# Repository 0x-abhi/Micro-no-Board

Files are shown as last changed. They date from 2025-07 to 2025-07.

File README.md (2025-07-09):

# Micro-no Board (µNO Board)- An Open Source Arduino-Compatible Development Platform

Welcome to the official documentation for the **µNO Board** (pronounced "Micro-no Board"). This open-source project presents a minimalistic, hardware-level implementation of the popular Arduino Uno, centered around the **ATmega328P-PU** microcontroller. Engineered and documented by **Abhishek Tomar**, this project is a comprehensive platform for electronics students and embedded systems learners seeking to understand the internal architecture and design of a microcontroller development board.

---

## 📚 Table of Contents

1. [Project Overview](#project-overview)
2. [Technical Features](#technical-features)
3. [Detailed Schematic Breakdown](#detailed-schematic-breakdown)

   * [Power Supply Circuit](#power-supply-circuit)
   * [Microcontroller Core](#microcontroller-core)
   * [Oscillator Configuration](#oscillator-configuration)
   * [Reset Mechanism](#reset-mechanism)
   * [FTDI Serial Programming Header](#ftdi-serial-programming-header)
   * [ISP Bootloader Interface](#isp-bootloader-interface)
   * [Status LED Indicator](#status-led-indicator)
4. [Arduino to ATmega328P Pin Mapping](#arduino-to-atmega328p-pin-mapping)
5. [Burning the Bootloader](#burning-the-bootloader)
6. [Uploading Programs via FTDI](#uploading-programs-via-ftdi)
7. [Understanding ISP and FTDI Protocols](#understanding-isp-and-ftdi-protocols)
8. [Accessing Design Files](#accessing-design-files)
9. [Contributions and Collaboration](#contributions-and-collaboration)
10. [License](#license)

---

## 🔍 Project Overview

The **µNO Board** replicates the functionality of the Arduino Uno but strips it to its essentials. Rather than relying on a premade Arduino module, this project demonstrates the discrete components necessary to build a fully functional development board from the ground up:

* Power regulation and filtering
* Stable clock generation
* GPIO and ADC decoupling
* Reset and auto-reset mechanisms
* Programming via serial (FTDI) or SPI (ISP)

It serves as both a learning tool and a production-ready embedded platform.

---

## ⚙️ Technical Features

* **Microcontroller**: ATmega328P-PU (8-bit AVR RISC architecture)
* **Voltage Regulation**: AMS1117-5.0V LDO regulator
* **System Clock**: External 16 MHz crystal
* **Programming Interfaces**: FTDI (UART) and ISP (SPI)
* **Manual Reset Button**: Physical switch for hardware resets
* **Input Voltage Range**: 6V to 15V (via VIN pin)
* **Regulated Output**: +5V for MCU and peripherals
* **GPIO Access**: Digital pins D0-D13, Analog pins A0-A5
* **Status Indicator**: Onboard LED that Indicates power ON/OFF

---

## 🔧 Detailed Schematic Breakdown

### 🔌 Power Supply Circuit

* **AMS1117-5.0V Regulator (U2)**

  * Converts input voltage (up to 15V) to 5V regulated output.
  * Essential for powering the MCU and peripherals.
* **Input/Output Capacitors**:

  * **C7, C8 (10uF)**: Stabilize input (VIN) and output (VOUT).
  * Filter transient fluctuations and reduce switching noise.

### 🧠 Microcontroller Core (ATmega328P)

* **Power Pins**:

  * **VCC (Pin 7)**: Main power input
  * **AVCC (Pin 20)**: Power supply for the ADC block
  * **GND (Pins 8 & 22)**: Common ground
* **Bypass Capacitors**:

  * **C3, C4, C6 (100nF)**: Placed near VCC and AVCC to suppress high-frequency noise.

### ⏱️ Oscillator Configuration

* **Crystal Oscillator (Y1, 16 MHz)**

  * External clock source for the MCU, ensures stable system timing
* **Load Capacitors (C1, C2 = 22pF)**

  * Ensure proper startup and oscillation of the crystal

### 🔁 Reset Mechanism

* **R1 (10kΩ)**: Pull-up resistor on RESET pin
* **SW1**: Push-button reset (pulls RESET to GND when pressed)
* **C5 (100nF)**: Coupled with FTDI DTR pin for auto-reset during code upload

### 🔄 FTDI Serial Programming Header (J5)

* **6-pin Header**: GND, VCC, RX, TX, DTR, CTS
* **Function**: Enables uploading sketches via UART after bootloader is flashed
* **Connection Tip**: Ensure TX (FTDI) connects to RX (MCU) and vice versa

### 💾 ISP Bootloader Interface (J1)

* **Standard 6-pin ISP Header**

  * MISO, MOSI, SCK, RESET, VCC, GND
* **Purpose**: Used for flashing the bootloader or burning hex files directly via SPI

---

## 🧩 Arduino to ATmega328P Pin Mapping

| Arduino | ATmega328P Pin | Port | Description |
| --- | --- | --- | --- |
| D0 | 2 | PD0 | UART RX |
| D1 | 3 | PD1 | UART TX |
| D2-D7 | 4-9 | PD2-PD7 | Digital I/O |
| D8-D13  | 14-19 | PB0-PB5 | SPI & I/O |
| A0-A5 | 23-28 | PC0-PC5 | ADC & I2C |
| RESET | 1 | PC6 | System Reset |
| AREF | 21 | - | Analog Reference |

---

## 🔥 Burning the Bootloader

### 💡 What is a Bootloader?

A bootloader is a small program that resides in the MCU’s flash memory, allowing firmware to be uploaded via UART rather than ISP.

### 🔧 Required Tools

* USBasp Programmer or Arduino-as-ISP

### 🧭 Step-by-Step Guide

1. Connect the ISP header on the board to your programmer.
2. Launch Arduino IDE.
3. Go to **Tools > Board > Arduino Uno**.
4. Under **Programmer**, select **USBasp** (or Arduino as ISP).
5. Click **Burn Bootloader**.

Once burned, your microcontroller can now be programmed through FTDI.

---

## ⬆️ Uploading Programs via FTDI

### 🛠️ Required Hardware

* FTDI USB-to-Serial Converter

### Wiring:

* FTDI TX → MCU RX
* FTDI RX → MCU TX
* DTR → RESET (via 100nF capacitor)
* VCC, GND connected properly

### Upload Steps:

1. Open Arduino IDE and select **Arduino Uno** as the board.
2. Choose the correct **COM Port**.
3. Click **Upload**.

The auto-reset circuit will handle entry into the bootloader automatically.

---

## 🧠 Understanding ISP and FTDI Protocols

### ISP (In-System Programming)

* **Protocol**: SPI-based (MOSI, MISO, SCK)
* **Use Case**: Burning bootloaders or uploading compiled firmware directly
* **Requires**: External programmer

### FTDI (USB-to-UART)

* **Protocol**: UART-based (TX/RX)
* **Use Case**: Uploading code to bootloaded MCUs
* **Advantage**: No extra hardware once bootloader is installed

---
## 🔮 Future Improvements and Expansion Ideas

As a learning platform and minimal Arduino-compatible board, the µNO Board has room for useful upgrades. Here are some potential enhancements that could improve its functionality, usability, and professional quality:

### 🔧 Hardware Improvements

- **⚡ Onboard USB-to-Serial (FTDI)**  
  Add a built-in CH340 or CP2102 IC for USB programming, eliminating the need for an external FTDI adapter.

- **🔋 3.3V Voltage Regulator**  
  Add an LDO regulator (e.g., AMS1117-3.3V) to support 3.3V sensors or modules on the same board.

- **🛡️ Reverse Polarity Protection**  
  Include a Schottky diode or P-MOSFET to protect the board from accidental reverse voltage input.

- **🧲 TVS Diodes or ESD Protection**  
  Protect sensitive GPIOs and the USB interface from electrostatic discharge or voltage spikes.

- **📦 Mounting Hole Grounding**  
  Connect metal mounting holes to GND for improved shielding and mechanical stability.

- **🧠 Additional GPIO Headers / Expansion Ports**  
  Break out I2C, SPI, ADC, and power lines to dedicated connectors for sensor/module expansion.

---

### 🖥️ Firmware & Bootloader Enhancements

- **⏱️ Optiboot Bootloader**  
  Use the smaller Optiboot variant to save flash memory and enable faster serial uploads (up to 115200 baud).

- **🧩 Arduino Board Package Support**  
  Create a custom board definition file (`boards.txt`) to add µNO as an official option in the Arduino IDE.

---

These enhancements can transform the µNO Board from a minimalist learning tool into a feature-rich, professional-grade embedded system. Explore, experiment, and evolve your design! 🚀

---

## 📁 Accessing Design Files

Your repository includes the following:

* `KiCad/`: Schematic and PCB design files
* `Gerber/`: Fabrication-ready output files
* `3D_Images/`: Visual renders of the board
* `README.md`: This documentation

📸 Board Images:

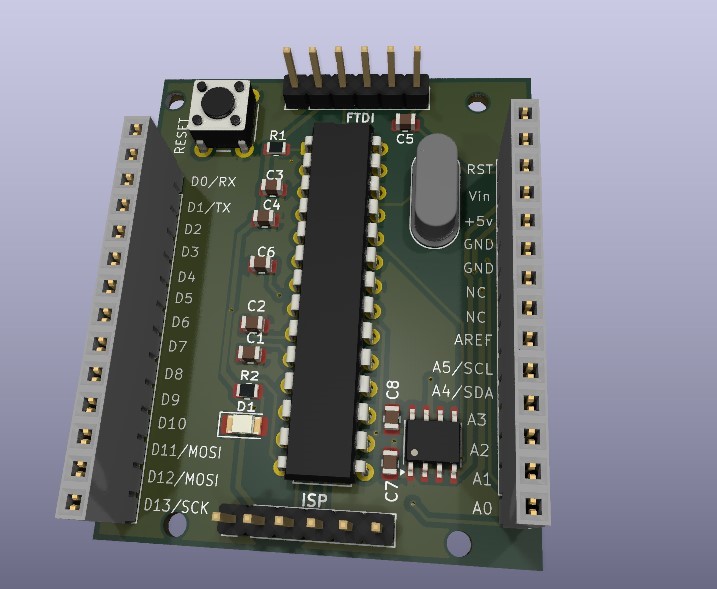
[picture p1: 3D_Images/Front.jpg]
Front View
* 
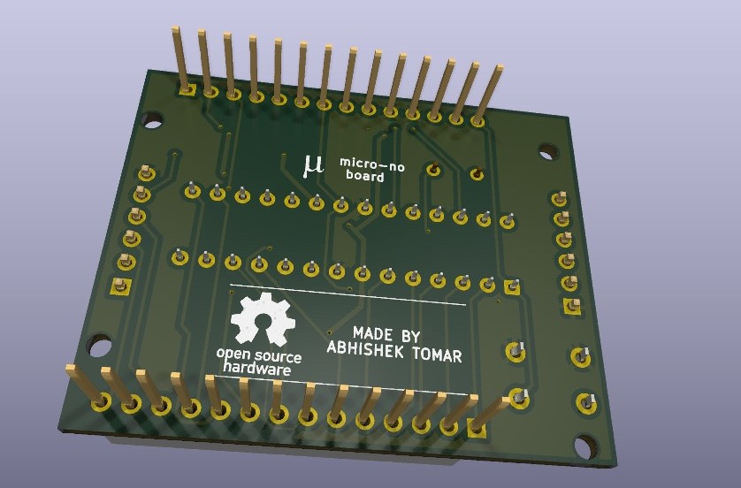
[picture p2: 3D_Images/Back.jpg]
Back View
* 
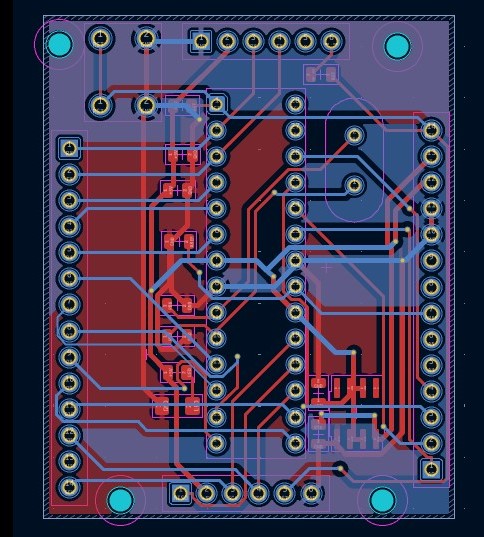
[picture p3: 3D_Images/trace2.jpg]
PCB Traces
* 

---

## 🤝 Contributions and Collaboration

Contributions are welcome! Feel free to fork the repository, submit pull requests, or raise issues for bugs, suggestions, or improvements.

---

## 📜 License

This project is licensed under the **CERN-OHL-S v2** open hardware license. This ensures:

* Freedom to study, modify, manufacture, and distribute
* Requirement to share changes under the same license

---

❤️ Created with passion by Abhishek Tomar — Just a learner like you.

🌟 **Support This Project!**

If this project helped you learn, build, or get inspired, please ⭐ star the repository and share it!

Together, we make open hardware accessible and empowering for all. 💪✨

Happy Hacking 🚀

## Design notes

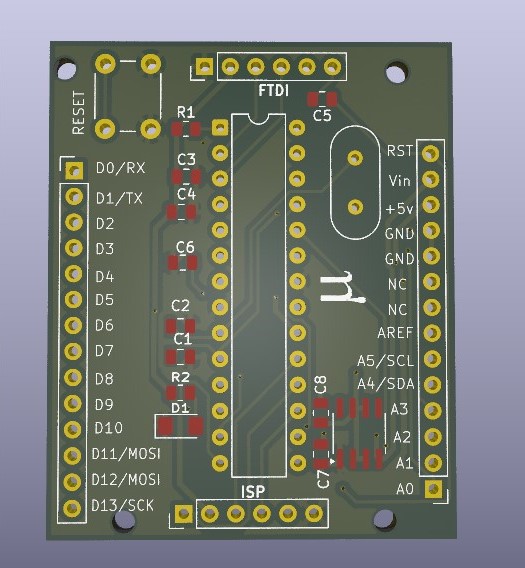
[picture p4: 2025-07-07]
3D_Images/PCB.jpg

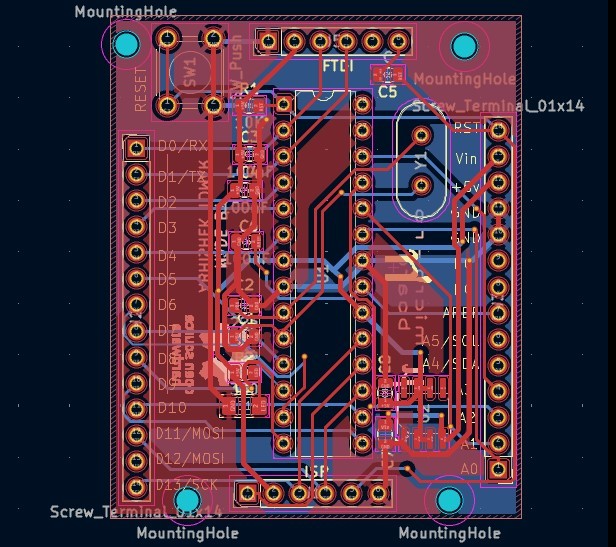
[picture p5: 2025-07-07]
3D_Images/trace1.jpg

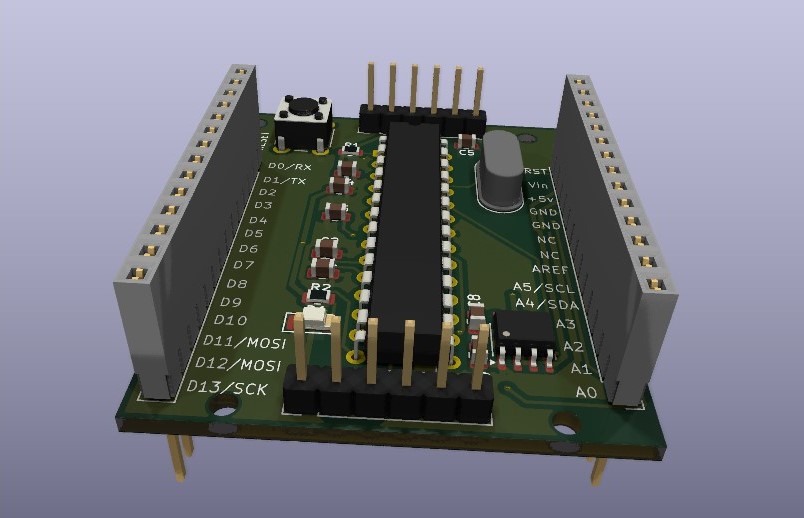
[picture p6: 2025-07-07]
3D_Images/Side.jpg

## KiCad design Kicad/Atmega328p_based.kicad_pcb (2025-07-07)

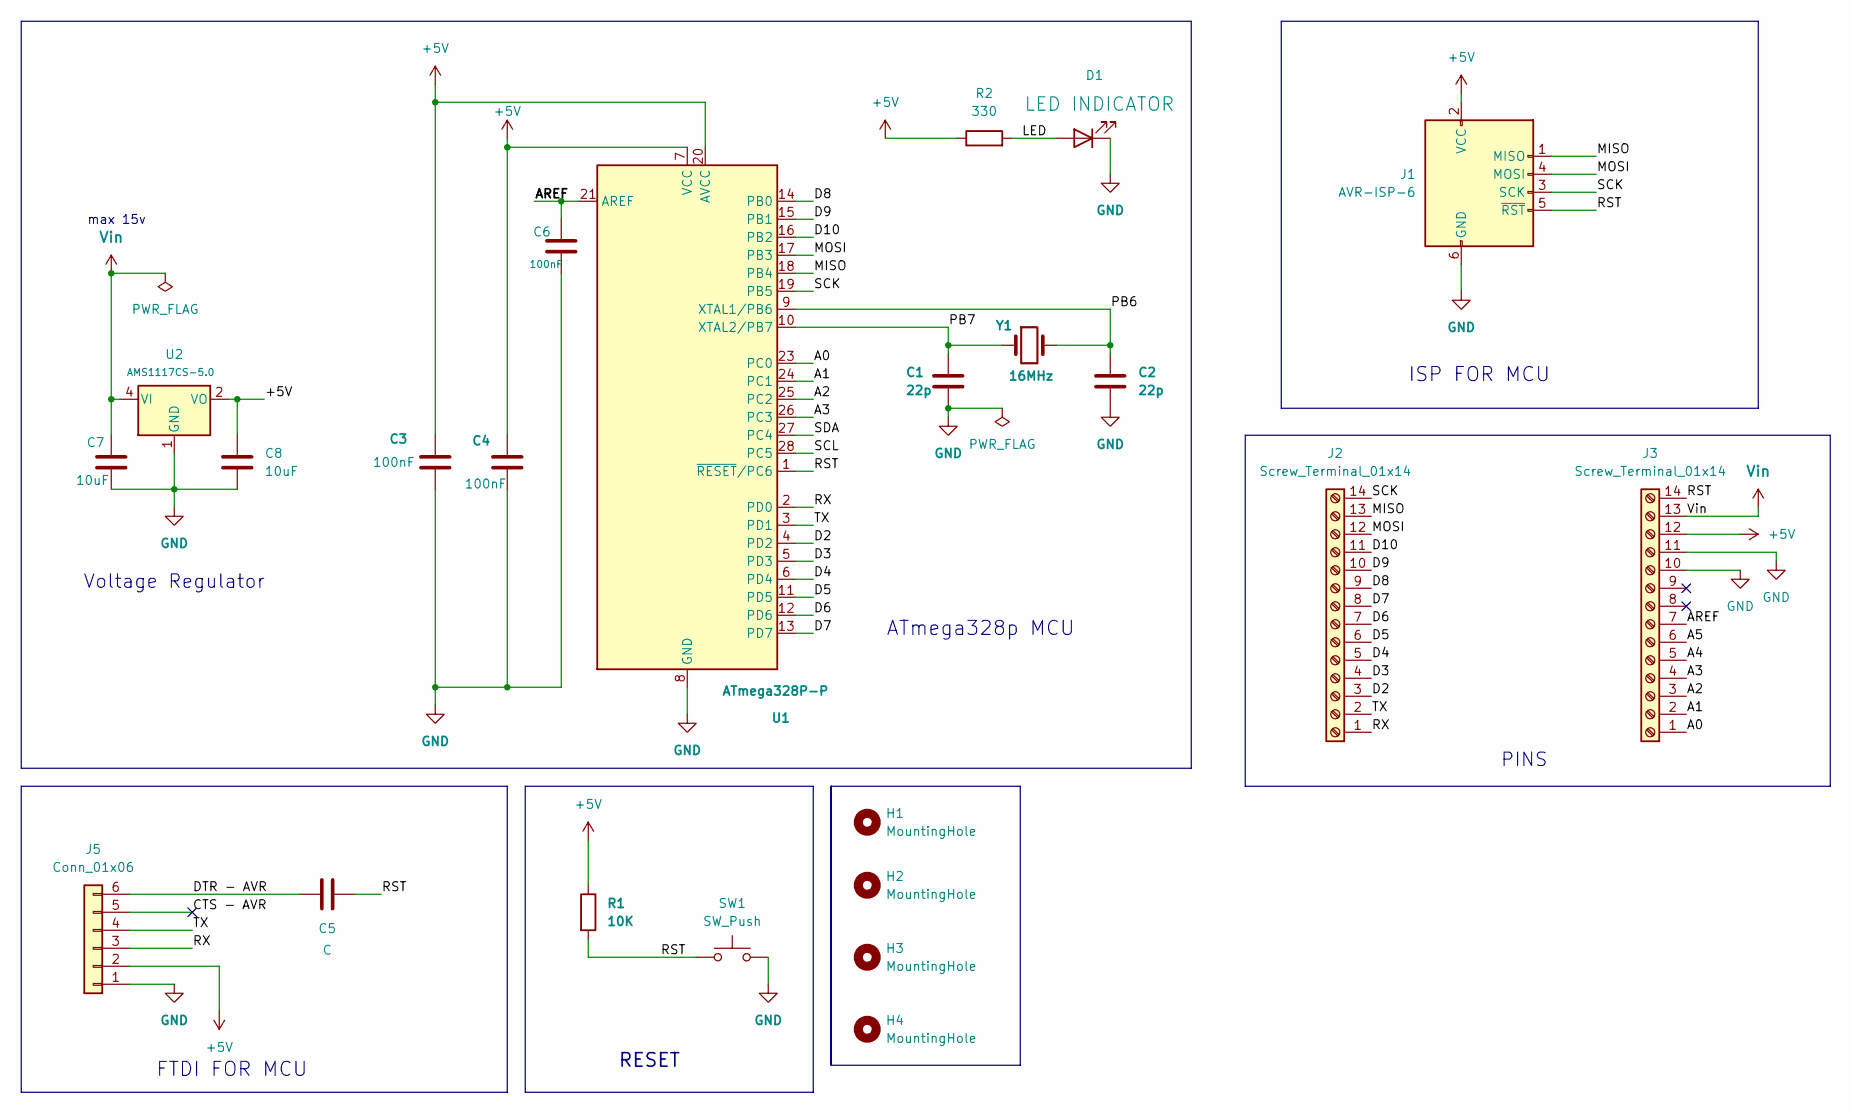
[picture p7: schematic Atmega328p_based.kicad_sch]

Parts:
C1, C2: 22p; C_0805_2012Metric
C3, C4, C6: 100nF; C_0805_2012Metric
C5: C; C_0805_2012Metric
C7, C8: 10uF; C_0805_2012Metric
D1: LED INDICATOR; LED_1206_3216Metric_Pad1.42x1.75mm_HandSolder
H1, H2, H3, H4: MountingHole; MountingHole_2.2mm_M2
J1: AVR-ISP-6; PinHeader_1x06_P2.54mm_Vertical
J2, J3: Screw_Terminal_01x14; PinHeader_1x14_P2.54mm_Vertical
J5: Conn_01x06; PinHeader_1x06_P2.54mm_Vertical
R1: 10K; R_0805_2012Metric
R2: 330; R_0805_2012Metric
SW1: SW_Push; SW_PUSH_6mm
U1: ATmega328P-P; DIP-28_W7.62mm
U2: AMS1117CS-5.0; SOIC-8_3.9x4.9mm_P1.27mm
Y1: 16MHz; Crystal_HC49-4H_Vertical

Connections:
+5V: C3.1, C4.1, C8.1, J1.2 (VCC), J3.12, J5.2, R1.1, R2.1, U1.7 (VCC), U1.20 (AVCC), U2.2 (VO), U2.3 (VO), U2.6 (VO), U2.7 (VO)
/ MOSI: J1.4 (MOSI), J2.12, U1.17 (PB3)
/A0: J3.1, U1.23 (PC0)
/A1: J3.2, U1.24 (PC1)
/A2: J3.3, U1.25 (PC2)
/A3: J3.4, U1.26 (PC3)
/A4: J3.5
/A5: J3.6
/AREF: C6.2, J3.7, U1.21 (AREF)
/CTS - AVR: J5.5
/D2: J2.3, U1.4 (PD2)
/D3: J2.4, U1.5 (PD3)
/D4: J2.5, U1.6 (PD4)
/D5: J2.6, U1.11 (PD5)
/D6: J2.7, U1.12 (PD6)
/D7: J2.8, U1.13 (PD7)
/D8: J2.9, U1.14 (PB0)
/D9: J2.10, U1.15 (PB1)
/D10: J2.11, U1.16 (PB2)
/DTR - AVR: C5.2, J5.6
/LED: D1.2 (A), R2.2
/PB6: C2.1, U1.9 (XTAL1/PB6), Y1.2
/PB7: C1.1, U1.10 (XTAL2/PB7), Y1.1
/RST: C5.1, J1.5 (~RST), J3.14, R1.2, SW1.1, U1.1 (~RESET/PC6)
/RX: J2.1, J5.3, U1.2 (PD0)
/SCK: J1.3 (SCK), J2.14, U1.19 (PB5)
/SCL: U1.28 (PC5)
/SDA: U1.27 (PC4)
/TX: J2.2, J5.4, U1.3 (PD1)
GND: C1.2, C2.2, C3.2, C4.2, C6.1, C7.2, C8.2, D1.1 (K), J1.6 (GND), J3.10, J3.11, J5.1, SW1.2, U1.8 (GND), U1.22 (GND), U2.1 (GND)
Vin: C7.1, J3.13, U2.4 (VI)

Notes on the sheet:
ATmega328p MCU
max 15v
FTDI FOR MCU
RESET
ISP FOR MCU
PINS
Voltage Regulator

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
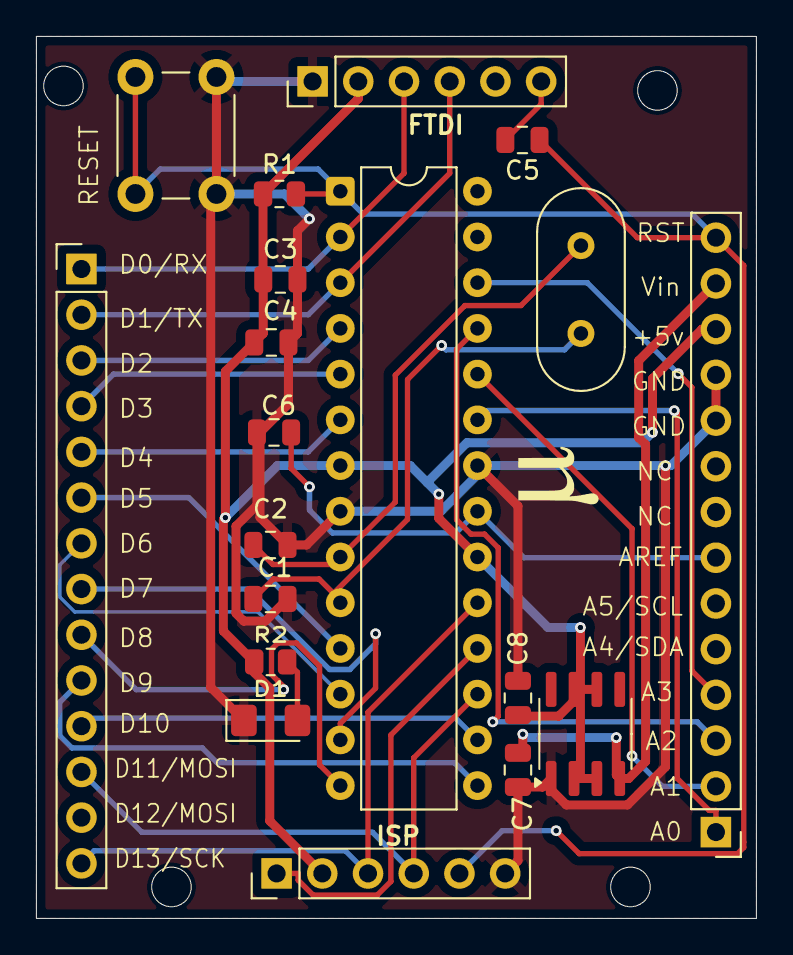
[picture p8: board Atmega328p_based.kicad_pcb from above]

Board: 2 copper layers, 40.0 x 49.0 mm, 23 parts (0 on the bottom side), 27 nets.
